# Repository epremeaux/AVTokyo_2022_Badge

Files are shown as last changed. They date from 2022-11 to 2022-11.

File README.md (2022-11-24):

## AVTokyo 2022 event badge
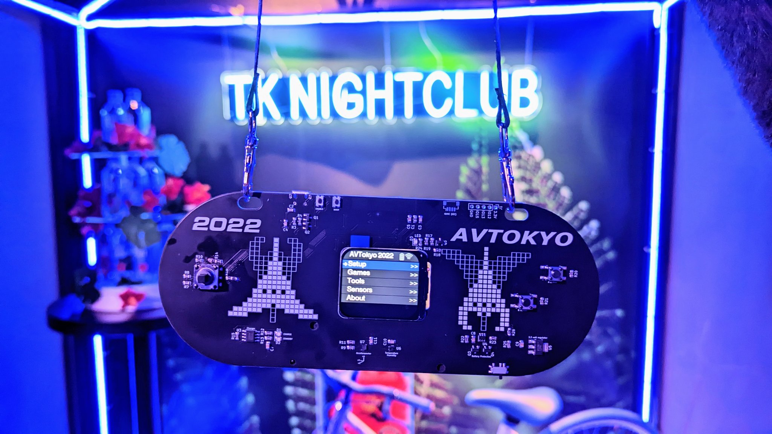
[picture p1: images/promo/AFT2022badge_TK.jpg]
Badge in front of the TKNightclub neon sign


### MQTT enabled, Hacker tools, Sensors and Games on ESP32
The AVTokyo 2022 event attendee badge was designed and produced by VPCAsia. Our vision was to provide a useful tool for the attendee not only at the event, but far into the future.

It is based on an 8MB ESP32 with 280x240 pixel TFT full color display (sourced from smart watches). Additionally, it includes a joystick (4 directions plus “press to select”), two game buttons (B and A), and two sensors (Temperature/Humidity and Accelerometer). Finally, the device is fully battery powered, relying on an 18650 style Li-ion battery with associated protections and USB charging.

The software runs a variety of open source Arduino libraries. In particular, we utilized [tcMenu](https://www.thecoderscorner.com/products/arduino-libraries/tc-menu/) and TFT_eSPI to provide all of our software UI, and Adafruit libraries to manage sensors and MQTT (Message Queue, Telemetry Transport).

While WiFi is connected and MQTT messaging is enabled, the badge will send Temperature, Humidity and Battery Voltage measurements to an MQTT server every 5 seconds (the interval is redefinable). Additionally, when you obtain a new best personal score on any game, the new score will be queued to be sent in the next MQTT post. While gaming, MQTT posting is temporarily disabled, in order to provide the best gaming experience.

Here is a video:
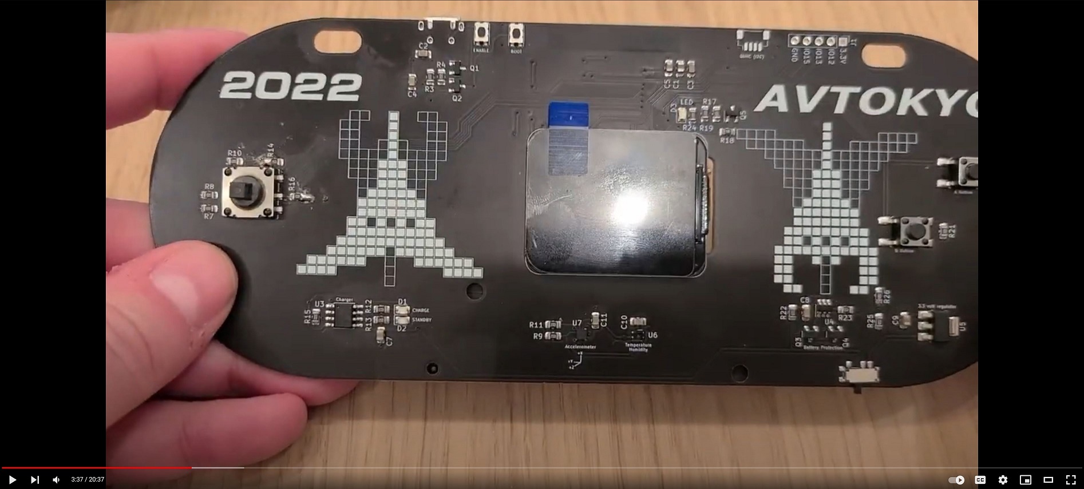
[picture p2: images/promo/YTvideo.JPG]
Watch the intro video (http://www.youtube.com/watch?v=L5FsP-4BdB0 "AVTokyo2022 Badge")


## Tour of the Board
Most of the badge components are self-explanatory, but I will attempt to highlight the main components and features. The circuitry between the joystick and screen is responsible for charging the battery (on the back). This is fed from the USB connector, and will charge the battery even when the badge is switched off. There are two LEDs, Standby and Charge. Once fully charged, the Charge LED will turn off and the Standby LED will light. These are rather bright! I started placing tape over my test units to dampend the brightness. ;)

Directly below the screen are the two sensors. On the right, we have an SHTC3 temperature and humidity sensor. On the left we have the KXTJ3-1057 accelerometer. Its not a particularly expensive device, so don't expect much. It's good enough for basic movement and orientation measurement. In the future, I hope to write some better drivers and filters for it to make the data more usable. At which point, I'll try to make a game using tilt/movement.

Above the power switch (bottom right) we have the battery protection circuits and voltage regulator which powers the board. The protection circuit is a very basic back to back mosfet configuration. The control IC *Should* cut power when the battery voltage gets below 3.2, but in my testing this turned out not to be the case. So, until I perform further tests, please dont trust this circuit to protect your battery from long term discharge. Remove the battery for storage.

Speaking of that power switch....   :(     Yes, now we know it's terrible. Attendee @mimura1133 found some alternate part numbers from Digikey if you have the skills to replace the switch. EG1215AA and CUS-12TB should fit. The part used on the badge is from G-Switch, MK-12C02-GXXX. We have yet to determine if this was a case of bad quality switches, or something in the reflow oven process made some of the switch plastics brittle. While this issue seemed considerable at the time of the event, we only had 42 total switch failures (of 400). The cracked resistor on the joystick was actually a higher failure rate.

Above the screen on the left we have the USB connector and associated ESP32 programming circuitry. This consists mainly of a USB to UART interface chip (CH340) and the Enable / Boot config buttons. Under normal circumstances using USB to program the badge, you should not need to bother with the buttons. If you get into a jam though, its nice to be able to manually trigger them. Additionally, the left button (enable) can be used as a reset button, so you dont have to toggle the power switch.
The USB connector can not only be used for programming but provides serial output from the ESP32 as well. There are some diagnostic messages as the badge goes through various tasks. The WiFi and Bluetooth scanners also output a lot of additional data here which cant possibly fit on the screen.

At the screen's top right corner we have a user LED and backlight control circuitry. The LED can be used for your own applications as well. We only use it to indicate the completion of the boot process (sort of a debugging tool for us).

Above the right side of the screen on the edge of the PCB we included some features for your own projects and future expansion. First, there is an I2C "Quiic" footprint. You will need to obtain and solder this yourself (was impossible at the time of production due to supply chain issues). This is a JST BM04B-SRSS connector or equivalent. 
To the right of the Quiic connector is a 5 pin header (2.54 mm pitch). This has ground, 3.3 volts, and three free GPIO from the ESP32. We are excited to see what you all come up with for these connections.

The back of the badge is dominated by the large 18650 lithium-ion battery holder at the bottom. Right in the middle is the ribbon cable for the screen. At top center we have the ESP32 module itself. This is an ESP32-Wroom-32 8MB part. Yes, it really IS 8MB. The firmware as flashed on the day of the event has a 4MB partition configuration. However, if you build fresh from this repository, it will build an 8Mb partition. All of our code now occupies only 20%! Lots of room left for more games, tools and custom apps. In the near future we will make some tutorials on how to add your project to the badge menu.

## Fixes to the production version
The PCB production and most of the component mounting was completed by JLCPCB. However, we still had some work to do. We glued the displays to the PCB and soldering the ribbon cable to the backside ourselves. Additionally, we mounted the battery case. However, you may notice some.. urr.. "Corrections" to some parts around the joystick. Unfortunately, I (Emery) made a mistake on the fill pattern, in which two pull-up resistors did not get connected to 3.3 Volts. So, we had to scrape away some of the solder mask and solder zero ohm jumpers to connect these resistors to the 3.3 volt fill. This added a LOT of additional work. The kicad files have been corrected. So if you attempt to produce the board yourself, don't worry.

We did experience a very unusual issue during production. Thankfully, I had created this a hardware test firmware before the final code was complete, so that we could test all functions before performing final firmware flashing. This test code included the Button Test (in the tools menu) as well as the Sensors page to confirm sensors were working.
The issue we found is that many (like, 1 of every 5 to 10) badges would indicate Left on the joystick, permanently. It took some time to identify the issue: The associated pull-up resistor (R8, on the left side of the joystick) was cracked. The crack is nearly impossible to see, even with a good magnifying lense. However, when we attempted to desolder it, it came off in two pieces! We were able to replace this resistor and managed to save 58 badges.

## About the Server
On our server side, we used a variety of services. It all starts by receiving the MQTT message in the MQTT server. From here, messages are written to a database using some custom Java.
From this database we then made web pages to output various statistics. In particular, we wanted to make a scoreboard for the two games included with the badge.
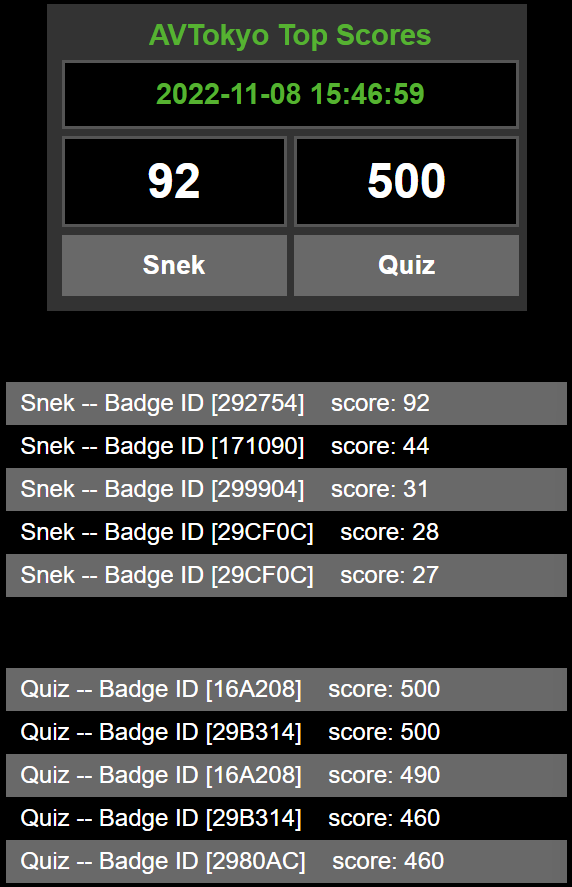
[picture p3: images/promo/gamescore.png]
Scores at the end of the event


MQTT is simply a message bucket service. Many other services can subscribe to it. In fact, the code which writes to the database simply subscribes to the MQTT messages. Because this concept is so flexible, other services can easily subscribe at the same time.

Node-Red is a very user friendly GUI based data application builder. It was a simple matter to create a Node-Red flow to subscribe to badge topics using wild cards, allowing us to easily gather temperature measurements from ALL badges at once for example. This same flow outputs a web page with gauges, plots and text data. Node-Red performance is not very quick, but because it is only subscribing to topics (and another service handles database work), it has no impact on MQTT or our database.
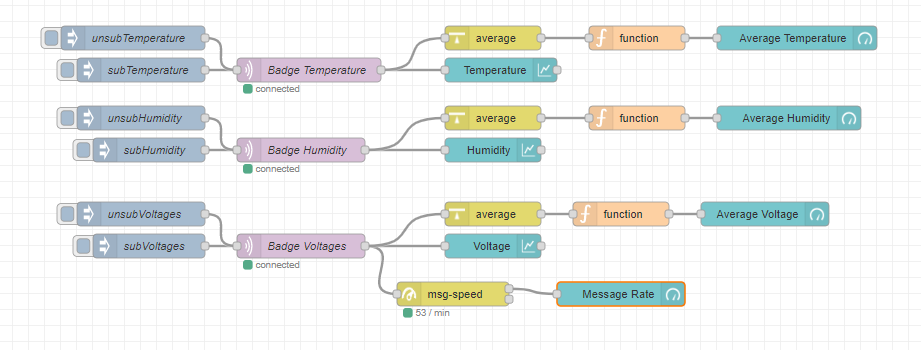
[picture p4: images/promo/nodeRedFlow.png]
Node-Red Flow

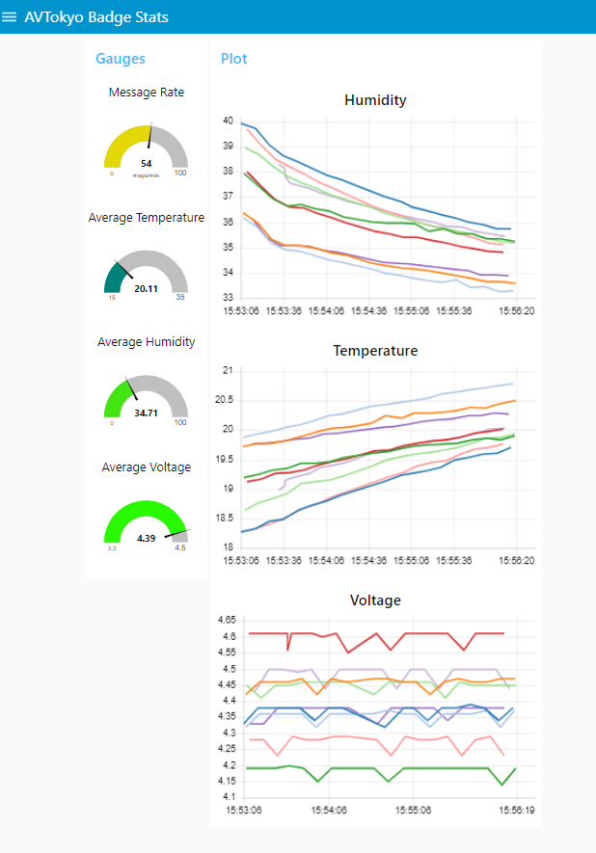
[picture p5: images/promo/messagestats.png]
Node-Red statistics page


### WiFi BugHunt
WE had one more game to play at the event: a WiFi BugHunt! These consisted of an ESP32 with battery pack hidden inside the nightclub (see AVTokyo_2022_Badge/Software/AVT_FindMe_Switcher/). Using the WiFi scanner tool in the badge (or your smartphone), players could seek out the three hidden WiFi access points. Once found, there was a QR code printed on the container of the WiFi AP. Scanning the code with your smartphone would bring you to a guest book web page, where you could sign that you found the AP and leave a comment. To make it more challenging, the APs occasionally dropped AP mode and joined local WiFi to send us an MQTT message containing the battery voltage, so we could monitor the devices in real time. It was quite entertaining to see all the script attacks people tried on our guestbook page ;)
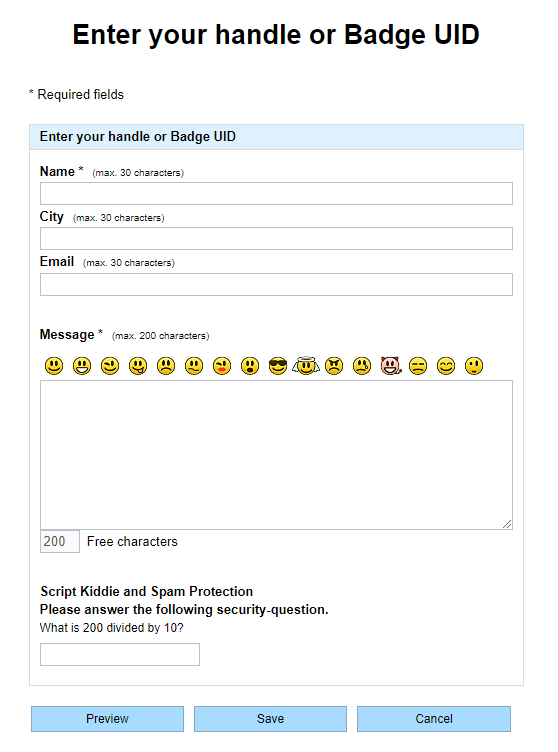
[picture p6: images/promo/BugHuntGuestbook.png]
BugHunt form

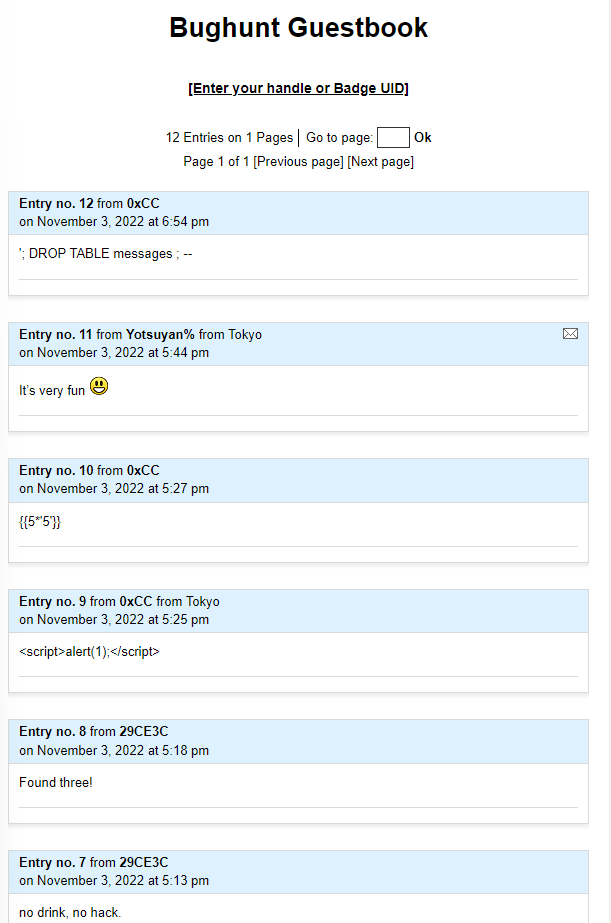
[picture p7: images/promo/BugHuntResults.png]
BugHunt results


## Getting the code up and running
The source code is "almost ready to run". You will need to install an editor such as Visual Studio Code. Within VSCode, add the PlatformIO extension. After opening the sourcecode folder, PlatformIO SHOULD download all the required extensions (mainly the Arduino framework and the ESP32 platform). All the required libraries are already included in the source code folder (.pio/libdeps/esp32dev/).
Depending on your initial VSCode and PlatformIO configuration, you MAY need to add "lorol/LittleFS_esp32@^1.0.6" to the platform.ini file, under the "lib_deps = " heading. If during compile you receive errors concerning LittleFS, either add it to the platform.ini file, or remove it (just add ; to the beginning of the line).

Additionally, you will need to create a "secrets.h" file like so:
```

//wifi
#define SECRET_SSID "your first AP"
#define SECRET_PASS "AP1 password"

#define SECRET_SSID2 "Second AP"
#define SECRET_PASS2 "AP2 password"

#define SECRET_SSID3 "third AP"
#define SECRET_PASS3 "AP3 password"

//mqtt
#define SECRET_SERVER "MQTT URL or IP" 

```

You can add as many WiFi access points as you want. Look at the MyWiFi.cpp file to add them to the array. The badge will first try to connect to whatever AP you have saved manually from the menu system. If that connection fails, it will then scan through the list given at the top of MyWiFi.cpp (the list is filled in from the secrets.h file). It will try to match any of these AP names to a scanned list available. If one matches, it will try to connect.

In addition to WiFi, you may want to point the badge to your own MQTT server. You may enter it manually in the menu, but you may prefer to hard code it. We have only defined the SECRET_SERVER keyword in the secrets.h file. This assumes an unsecured connection. So, you may want to modify MQTT_Sensors.cpp and secrets.h such that you can define a username and access key in secrets.h.

### UPDATE (22/11/24):

While experimenting with some badges, I found that SOME badges have 4MB ESP32 modules, and some have 8MB modules. Of course, we ORDERED 8MB modules. If you are attempting to compile and run this code and the following effects happen (after upload and reset), you likely have a 4MB module:

* red LED at the top right corner of the screen remains dimly light
* nothing displayed on screen
* when using the terminal, you see that the ESP is rapidly rebooting, with the following output: 
```
rst:0x3 (SW_RESET),boot:0x13 (SPI_FAST_FLASH_BOOT)
configsip: 0, SPIWP:0xee
clk_drv:0x00,q_drv:0x00,d_drv:0x00,cs0_drv:0x00,hd_drv:0x00,wp_drv:0x00
mode:DIO, clock div:2
load:0x3fff0030,len:1184
load:0x40078000,len:12776
load:0x40080400,len:3032
entry 0x400805e4
ets Jul 29 2019 12:21:46
```

PlatformIO is building an image set larger than the size of the flash storage area. However, it cannot by itself, verify the size. All the checksums are fine. You can confirm the size of your ESP's flash area yourself though. Look in the upload task terminal. When you hit the compile button (check mark on the bottom of VSCode window), one of hte first few lines will read:
HARDWARE: ESP32 240MHz, 320KB RAM, 4MB Flash
OR
HARDWARE: ESP32 240MHz, 320KB RAM, 8MB Flash

IF you were unlucky enough to get a 4MB module, we are so sorry.. but we cant control unscrupulous suppliers *(
What to do:
in the platformio.ini file, find the line which reads:

```
board_build.partitions = AVT_8MB_huge.csv
```

Change it to read:

```
board_build.partitions = huge_app.csv
```

This will use a standard partition table for a 4MB ESP32, where most of the space is devoted to a single app, plus bootloader. The base AVT code will occupy 51.5%, still leaving plenty of space for future enhancements.
By the way, this partition table is the one used in all of the badges on the day of the event. This is why I did not notice that we had a mix of 4MB and 8MB modules. So, I dont know yet what the statistics are on how many of you have each type.

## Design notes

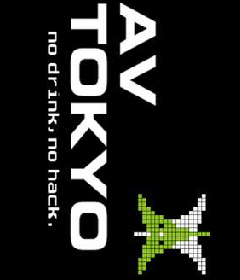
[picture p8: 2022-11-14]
images/pictures/ndnh277.png

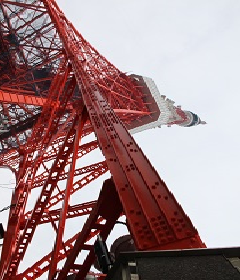
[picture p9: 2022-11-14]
images/pictures/TT1.png

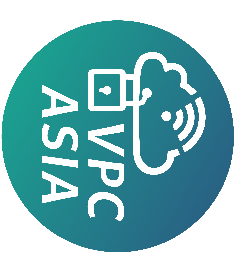
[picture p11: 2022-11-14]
images/pictures/VPCA.png

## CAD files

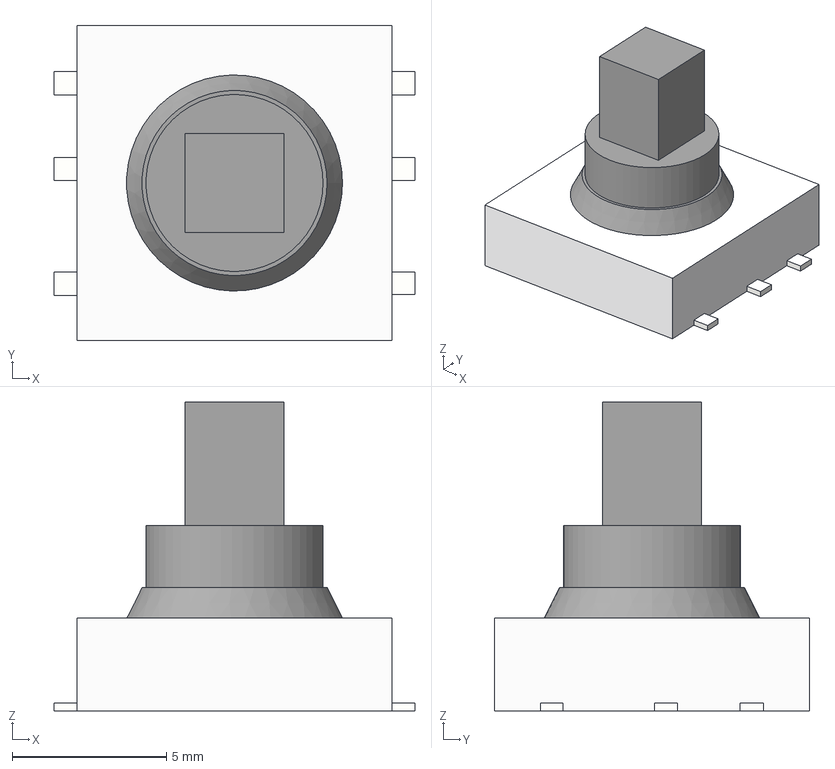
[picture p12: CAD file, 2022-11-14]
Kicad/3dmodels/AVTokyo/HROParts Multi-direction switch K1-1506SN-01.step
11.7 x 10.2 x 10.0 mm
stick
leads

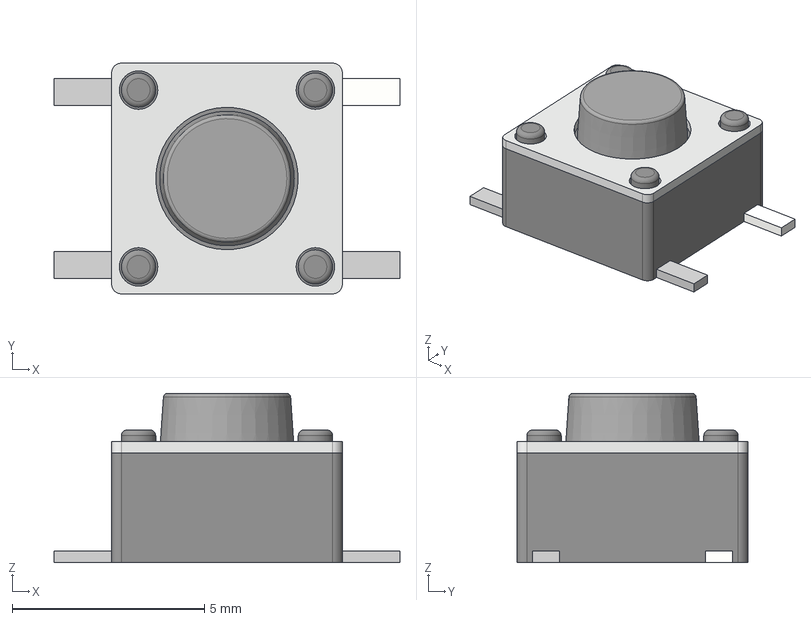
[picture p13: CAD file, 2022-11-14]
Kicad/3dmodels/AVTokyo/tact switch KH-6x6x5H v2.step
9.00 x 6.00 x 4.40 mm
toop plate
button
legs

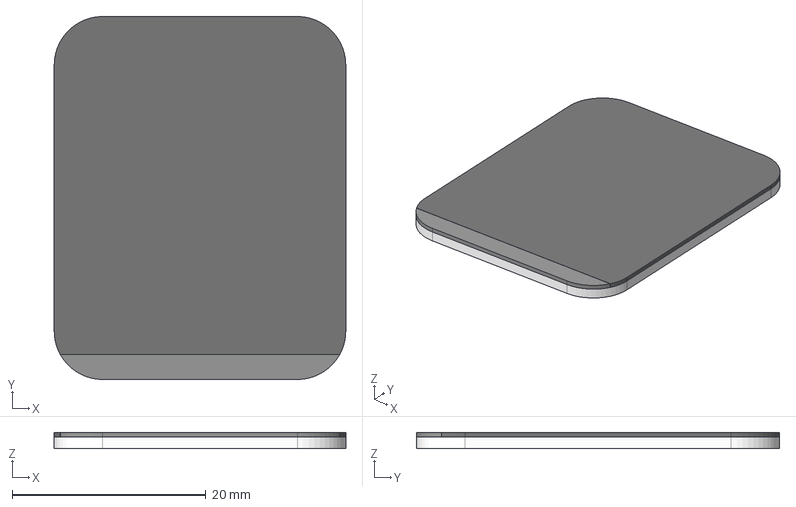
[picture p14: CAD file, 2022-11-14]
Kicad/3dmodels/AVTokyo/1.69 inch 240x280 v1.step
30.1 x 37.4 x 1.70 mm
LED Plate
glass
driverstrip

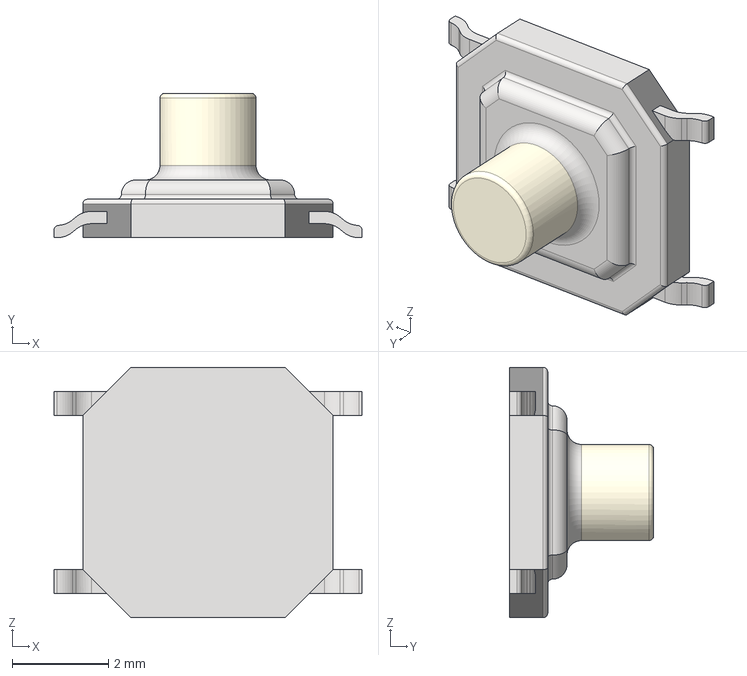
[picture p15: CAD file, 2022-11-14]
Kicad/3dmodels/AVTokyo/tact_switch_3mm.stp
6.40 x 3.00 x 5.20 mm

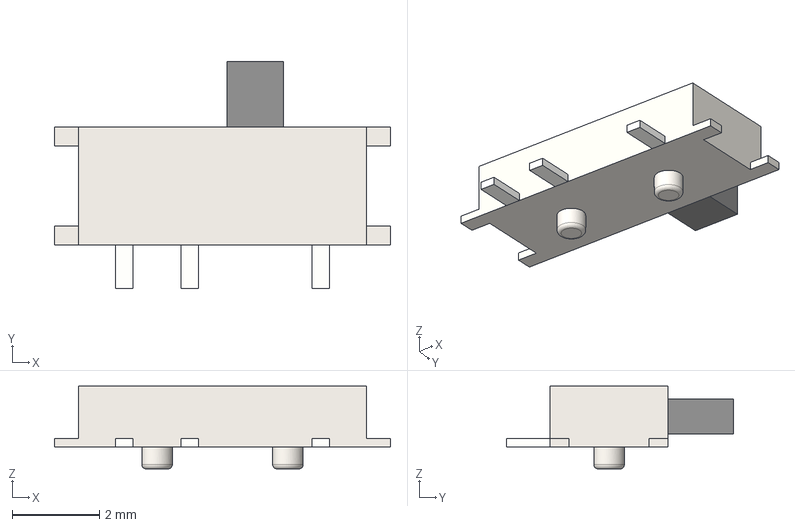
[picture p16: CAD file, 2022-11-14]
Kicad/3dmodels/AVTokyo/G-Switch MK-12C02-Gxxx.step
7.70 x 5.20 x 1.90 mm
Terminals
knob

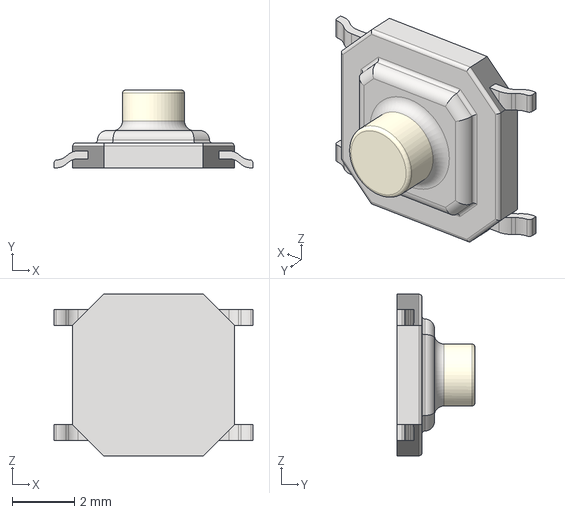
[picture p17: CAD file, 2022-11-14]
Kicad/3dmodels/AVTokyo/tact_switch_2.5mm.stp
6.40 x 2.50 x 5.20 mm

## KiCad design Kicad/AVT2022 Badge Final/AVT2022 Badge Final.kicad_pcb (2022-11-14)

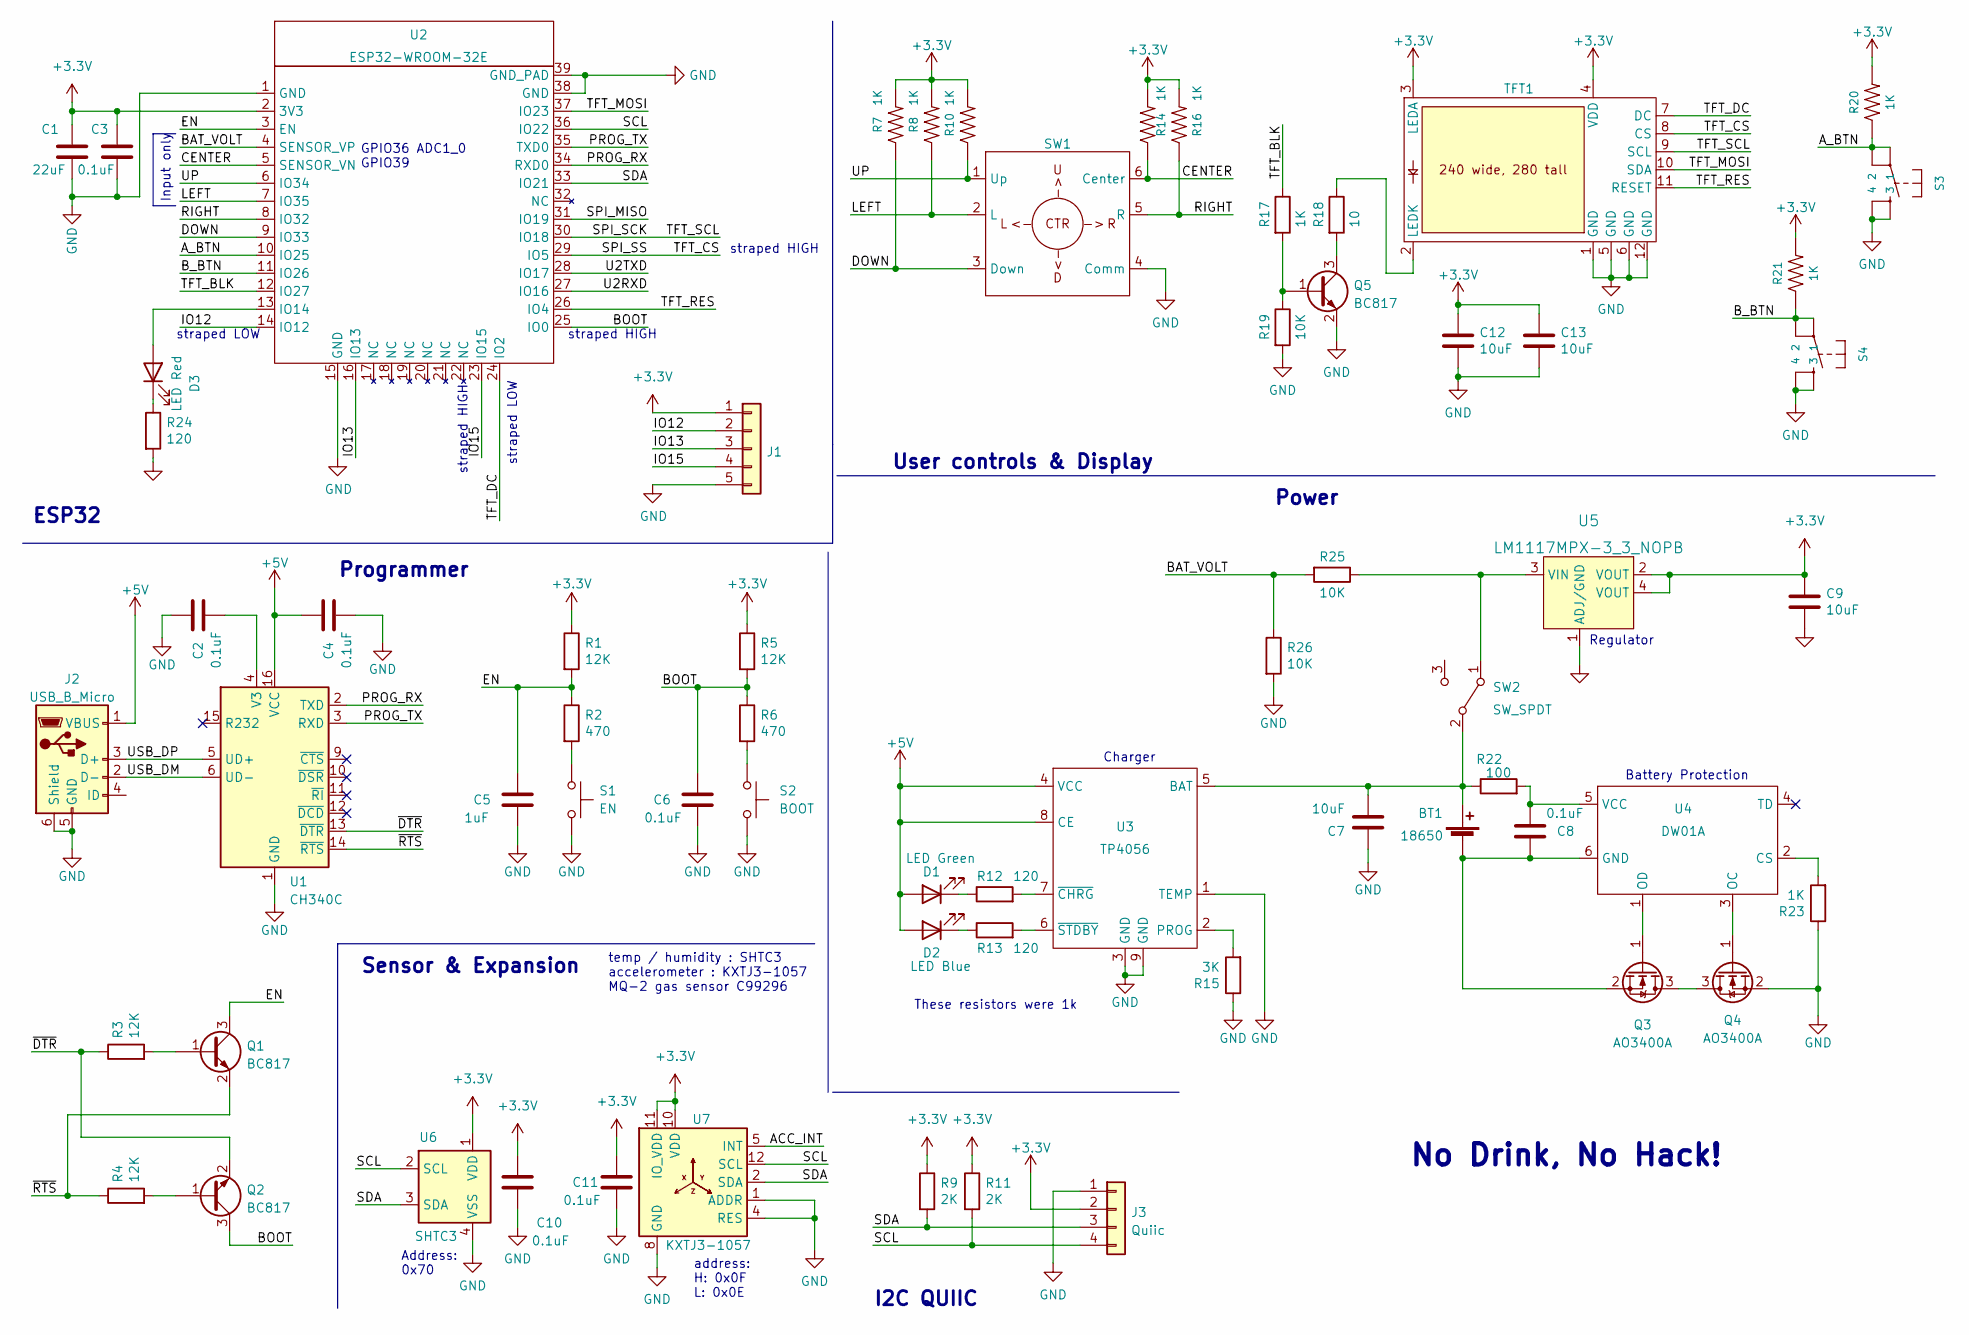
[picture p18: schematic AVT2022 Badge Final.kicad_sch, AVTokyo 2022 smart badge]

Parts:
BT1: 18650; BatteryHolder_Keystone_1042_1x18650; JLCPCB Status DO NOT POPULATE
C1: 22uF; C_0805_2012Metric_Pad1.18x1.45mm_HandSolder; JLCPCB# C89572
C2, C3, C4, C6, C8, C10, C11: 0.1uF; C_0805_2012Metric_Pad1.18x1.45mm_HandSolder; JLCPCB# C49678
C5: 1uF; C_0805_2012Metric_Pad1.18x1.45mm_HandSolder; JLCPCB# C28323
C7, C9, C12, C13: 10uF; C_0805_2012Metric_Pad1.18x1.45mm_HandSolder; JLCPCB# C15850
D1: LED Green; LED_0805_2012Metric; JLCPCB Status extended
D2: LED Blue; LED_0805_2012Metric; JLCPCB Status basic
D3: LED Red; LED_0805_2012Metric; JLCPCB Status basic
J1: Conn_01x05; PinHeader_1x05_P2.54mm_Vertical; JLC_Status DO NOT POPULATE
J2: USB_B_Micro; USB_Micro-AB_Molex_47590-0001; JLCPCB Status extended
J3: Quiic; JST_SH_BM04B-SRSS-TB_1x04-1MP_P1.00mm_Vertical; JLC_Status DO NOT POPULATE
Q1, Q2, Q5: BC817; SOT-23; JLCPCB Status extended
Q3, Q4: AO3400A; SOT-23; JLCPCB Status basic
R1, R3, R4, R5: 12K; R_0805_2012Metric_Pad1.20x1.40mm_HandSolder; JLCPCB# C17444
R2, R6: 470; R_0805_2012Metric_Pad1.20x1.40mm_HandSolder; JLCPCB# C17710
R7, R8, R10, R14, R16, R17, R20, R21, R23: 1K; R_0805_2012Metric_Pad1.20x1.40mm_HandSolder; JLCPCB# C17513
R9, R11: 2K; R_0805_2012Metric_Pad1.20x1.40mm_HandSolder; JLCPCB# C17604
R12, R13, R24: 120; R_0805_2012Metric_Pad1.20x1.40mm_HandSolder; JLCPCB# C17437
R15: 3K; R_0805_2012Metric_Pad1.20x1.40mm_HandSolder; JLCPCB# C17661
R18: 10; R_0805_2012Metric_Pad1.20x1.40mm_HandSolder; JLCPCB# C176204
R19, R25: 10K; R_0805_2012Metric_Pad1.20x1.40mm_HandSolder; JLCPCB# C17414
R22: 100; R_0805_2012Metric_Pad1.20x1.40mm_HandSolder; JLCPCB# C17408
R26: 10K; R_0805_2012Metric_Pad1.20x1.40mm_HandSolder; JLCPCB# C17621
S1: EN; SW_Push_1P1T_NO_CK_KMR2; JLCPCB Status extended
S2: BOOT; SW_Push_1P1T_NO_CK_KMR2; JLCPCB Status extended
S3, S4: MOMENTARY-SWITCH-SPST-2-SMD-5.2MM; Switch_Tactile_SMD_6x6mm; JLCPCB Status extended
SW1: navigation_switch_K1-1506SN-01; K1-1506SN-01; JLCPCB Status extended
SW2: SW_SPDT; MK-12C02-Gxxx SPDT SMD switch; JLCPCB Status extended
TFT1: TFT_240x280_raw_LH169I-IG01; TFT_240x280_raw_LH169I-IG01_BackSideMount; JLC_Status DO NOT POPULATE
U1: CH340C; SOIC-16_3.9x9.9mm_P1.27mm; JLCPCB Status extended
U2: ESP32-WROOM-32E; JLCPCB Status extended
U3: TP4056; TI_SO-PowerPAD-8; JLCPCB Status extemded
U4: DW01A; SOT-23-6; JLCPCB Status extemded
U5: LM1117MPX-3_3_NOPB; SOT-223; MPN LM1117MPX-3.3/NOPB; Digi-Key_PN LM1117MPX-3.3/NOPBCT-ND
U6: SHTC3; Sensirion_DFN-4-1EP_2x2mm_P1mm_EP0.7x1.6mm; JLCPCB# C194656
U7: KXTJ3-1057; Kionix_LGA-12_2x2mm_P0.5mm_LayoutBorder2x4y; JLCPCB# C442603

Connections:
+3.3V: C1.1, C3.1, C9.1, C10.1, C11.1, C12.1, C13.1, J1.1, J3.2, R1.1, R5.1, R7.2, R8.2, R9.1, R10.2, R11.1, R14.2, R16.2, R20.2, R21.2, TFT1.3 (LEDA), TFT1.4 (VDD), U2.2 (3V3), U5.2 (VOUT), U5.4 (VOUT), U6.1 (VDD), U7.3 (IO_VDD), U7.7 (VDD), U7.10 (VDD), U7.11 (IO_VDD)
+5V: C4.1, D1.2 (A), D2.2 (A), J2.1 (VBUS), U1.16 (VCC), U3.4 (VCC), U3.8 (CE)
/ACC_INT: U7.5 (INT)
/A_BTN: R20.1, S3.1, S3.2, U2.10 (IO25)
/BAT_VOLT: R25.2, R26.1, U2.4 (SENSOR_VP)
/BOOT: C6.1, Q2.3 (C), R5.2, R6.1, U2.25 (IO0)
/B_BTN: R21.1, S4.1, S4.2, U2.11 (IO26)
/CENTER: R14.1, SW1.6 (Center), U2.5 (SENSOR_VN)
/DOWN: R7.1, SW1.3 (Down), U2.9 (IO33)
/EN: C5.1, Q1.3 (C), R1.2, R2.1, U2.3 (EN)
/IO12: J1.2, U2.14 (IO12)
/IO13: J1.3, U2.16 (IO13)
/IO15: J1.4, U2.23 (IO15)
/LEFT: R8.1, SW1.2 (L), U2.7 (IO35)
/PROG_RX: U1.2 (TXD), U2.34 (RXD0)
/PROG_TX: U1.3 (RXD), U2.35 (TXD0)
/RIGHT: R16.1, SW1.5 (R), U2.8 (IO32)
/SCL: J3.4, R11.2, U2.36 (IO22), U6.2 (SCL), U7.12 (SCL)
/SDA: J3.3, R9.2, U2.33 (IO21), U6.3 (SDA), U7.2 (SDA)
/SPI_MISO: U2.31 (IO19)
/SPI_SCK: TFT1.9 (SCL), U2.30 (IO18)
/SPI_SS: TFT1.8 (CS), U2.29 (IO5)
/TFT_BLK: R17.1, U2.12 (IO27)
/TFT_DC: TFT1.7 (DC), U2.24 (IO2)
/TFT_MOSI: TFT1.10 (SDA), U2.37 (IO23)
/TFT_RES: TFT1.11 (RESET), U2.26 (IO4)
/U2RXD: U2.27 (IO16)
/U2TXD: U2.28 (IO17)
/UP: R10.1, SW1.1 (Up), U2.6 (IO34)
/USB_DM: J2.2 (D-), U1.6 (UD-)
/USB_DP: J2.3 (D+), U1.5 (UD+)
/~DTR: Q2.2 (E), R3.1, U1.13 (~DTR)
/~RTS: Q1.2 (E), R4.1, U1.14 (~RTS)
GND: C1.2, C2.1, C3.2, C4.2, C5.2, C6.2, C7.1, C9.2, C10.2, C11.2, C12.2, C13.2, J1.5, J2.5 (GND), J2.6 (Shield), J3.1, Q4.2 (S), Q5.2 (E), R15.1, R19.2, R23.1, R24.2, R26.2, S1.2, S2.2, S3.3, S3.4, S4.3, S4.4, SW1.4 (Comm), TFT1.1 (GND), TFT1.5 (GND), TFT1.6 (GND), TFT1.12 (GND), U1.1 (GND), U2.1 (GND), U2.15 (GND), U2.38 (GND), U2.39 (GND_PAD), U3.1 (TEMP), U3.3 (GND), U3.9 (GND), U5.1 (ADJ/GND), U6.4 (VSS), U7.1 (ADDR), U7.4 (RES), U7.6 (GND), U7.8 (GND), U7.9 (GND)
unnamed: BT1.1 (+), C7.2, R22.1, SW2.2 (B), U3.5 (BAT)
unnamed: BT1.2 (-), C8.1, Q3.2 (S), U4.6 (GND)
unnamed: C2.2, U1.4 (V3)
unnamed: C8.2, R22.2, U4.5 (VCC)
unnamed: D1.1 (K), R12.1
unnamed: D2.1 (K), R13.1
unnamed: D3.1 (K), R24.1
unnamed: D3.2 (A), U2.13 (IO14)
unnamed: Q1.1 (B), R3.2
unnamed: Q2.1 (B), R4.2
unnamed: Q3.1 (G), U4.1 (OD)
unnamed: Q3.3 (D), Q4.3 (D)
unnamed: Q4.1 (G), U4.3 (OC)
unnamed: Q5.1 (B), R17.2, R19.1
unnamed: Q5.3 (C), R18.2
unnamed: R2.2, S1.1
unnamed: R6.2, S2.1
unnamed: R12.2, U3.7 (~CHRG)
unnamed: R13.2, U3.6 (~STDBY)
unnamed: R15.2, U3.2 (PROG)
unnamed: R18.1, TFT1.2 (LEDK)
unnamed: R23.2, U4.2 (CS)
unnamed: R25.1, SW2.1 (A), U5.3 (VIN)

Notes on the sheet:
straped HIGH
straped LOW
ESP32
Charger
GPIO36 ADC1_0 GPIO39
Regulator
temp / humidity : SHTC3 accelerometer : KXTJ3-1057 MQ-2 gas sensor C99296
Power
Address: 0x70
Input only
Battery Protection
These resistors were 1k
address: H: 0x0F L: 0x0E
Programmer
I2C QUIIC
No Drink, No Hack!
Sensor & Expansion
User controls & Display

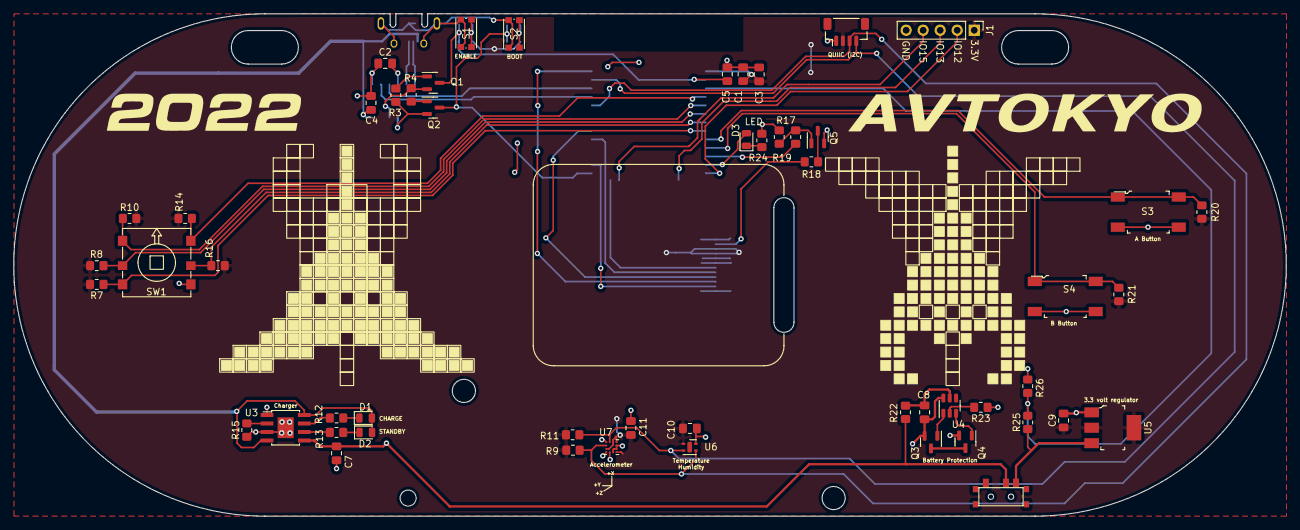
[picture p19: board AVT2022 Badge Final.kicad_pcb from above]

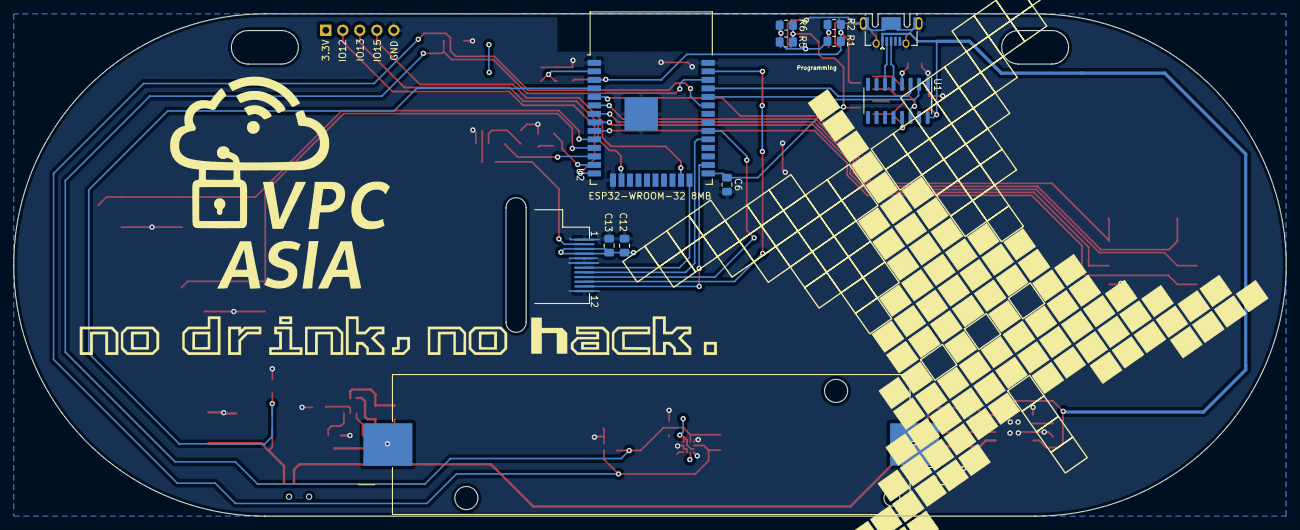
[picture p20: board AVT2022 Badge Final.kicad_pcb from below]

Board: 2 copper layers, 190.0 x 75.0 mm, 65 parts (11 on the bottom side), 53 nets.

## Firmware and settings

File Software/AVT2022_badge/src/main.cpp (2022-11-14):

#include <Arduino.h>
#include "AVT2022_badge_menu.h"
#include "TFT_eSPI.h"

//#include our application header files
#include "variables.h"
#include "MyWiFi.h"
#include "ButtonIcons.h"
#include "BatteryWidget25x15.h"
#include "WiFiWidget28x20.h"
#include "life.h"
#include "scanner.h"
#include "quiz.h"
#include "snek.h"
#include "Plotter.h"
#include "MQTT_Sensors.h"
#include "SaveScreen.h"
#include "Preferences.h"
// images
#include "avtokyo.h"
#include "vpcasia.h"

#define MAX_IMAGE_WIDTH 240
#define MAX_IMAGE_HEIGHT 280

Preferences Global::preferences;
// Note: Key name is limited to 15 chars.
// preferences / user
String UserName;
// preferences / system
int BackLight;
int BadgeMode;

int WifiConnected = false;

int Global::FWversion = 1;

// preferences / games
// preferences / scores

uint16_t Global::TODcounter = 0;

// hardware config
#define RIGHT_PIN 32 // 36
#define DOWN_PIN 33
#define UP_PIN 34
#define LEFT_PIN 35
#define SELECT_PIN 39
#define A_PIN 25 // A button
#define B_PIN 26
#define USR_LED 14

// backlight dimming
#define BACKLIGHT_PIN 27
const int freq = 1000;
const int ledChannel = 0;
const int resolution = 8;

/************ Titlebar Widgets ******************/
//  padding widget to push icons left. Make this the last widget in chain
TitleWidget BatteryWidget(iconsBattery, 5, 15, 25);
TitleWidget WiFiWidget(iconsWiFi, 5, 28, 20, &BatteryWidget);
TitleWidget iconspadWidget(iconsWiFi, 5, 16, 12, &WiFiWidget);


/************ Configuring WiFi ******************/
char Global::WLAN_SSID[]; // changable ssid and pw
char Global::WLAN_PASS[];
bool Global::WiFi_Enable = true; // true = wifi enabled
bool Global::WiFi_Good = false;
bool Global::WiFi_DoReset = true;
bool Global::WiFi_DoDisable = false;
char Global::USER_ID[];


/************ TASK IDs ******************/
taskid_t Global::SenserUpdateTaskID;
taskid_t Global::ConnectWiFiTaskID;
taskid_t Global::PostMQTTTaskID;




/****************************************************************************
 *                      Helper functions
 ****************************************************************************/
void showImages()
{
    gfx.fillScreen(TFT_BLACK);
    gfx.pushImage(0, 0, MAX_IMAGE_WIDTH, MAX_IMAGE_HEIGHT, (uint8_t *)avtokyo_logo, true);
    delay(3500);
    gfx.fillScreen(TFT_BLACK);
    gfx.pushImage(0, 0, MAX_IMAGE_WIDTH, MAX_IMAGE_HEIGHT, (uint8_t *)vpcasia_logo, true);
    delay(3500);
    gfx.fillScreen(TFT_BLACK);
}


void ResetScreen(unsigned int encoderValue, RenderPressMode clicked)
{       // draws a screen to tell user the factory defaults have been restored
    if (Global::TODcounter == 0)
    {
        Global::TODcounter++;
        gfx.fillScreen(TFT_BLACK);
        gfx.setTextSize(1);
        gfx.setTextColor(TFT_WHITE);
        gfx.setCursor(50, 10);
        gfx.println("Factory settings");
        gfx.println("         restored");
    }
    delay(1000);
    Global::TODcounter = 0;
    renderer.giveBackDisplay();
}


void WipeAllPrefs()
{
    // clears out all preference namespaces.
    // upon reboot, the defaults will be re-applied
    Global::preferences.begin("User", false);
    Global::preferences.clear();
    Global::preferences.end();

    Global::preferences.begin("Network", false);
    Global::preferences.clear();
    Global::preferences.end();

    Global::preferences.begin("System", false);
    Global::preferences.clear();
    Global::preferences.end();

    Global::preferences.begin("MQTT", false);
    Global::preferences.clear();
    Global::preferences.end();

    Global::preferences.begin("Quiz", false);
    Global::preferences.clear();
    Global::preferences.end();

    Global::preferences.begin("Snek", false);
    Global::preferences.clear();
    Global::preferences.end();
    // nitification screen
    renderer.takeOverDisplay(ResetScreen);
}

void onPressed(uint8_t pin, bool heldDown)
{
    // This function must exist, even if it needs no additional code
    // it allows all of our buttons to be available to decode in games/tools
    // we can also do stuff like below, but this would print on every press.. its better to decode as needed in the game/tool
    // we also MUST have the below class (MyKeyListener), even though its empty.
    // in setup, we will add all the additional buttons we want to listen for and decode

    /* if (pin == A_PIN){
       Serial.println("A button polled");
     }
     if (pin == B_PIN){
       Serial.println("B button polled");
     }  */
}

class MyKeyListener : public SwitchListener
{
public:
    void onPressed(uint8_t pin, bool held) override
    {
    }

    void onReleased(uint8_t /*pin*/, bool held) override
    {
        // Called on key release
    }
} keyListener;



// some vars to cycle title widgets until code written to control them...
int widgetCounter = 0;
bool widgetDirUp = true;

void updateIconsTask()
{
    /* Battery range
     * From 4.25V to 3.6 volts
     * However the screen flickers a LOT and becomes very dim
     * Practical range is from 4.25 to 3.86V
     */
    // cludgy fix for the battery range. Voltage divider is not precision, and ESP32 ADC is terrible
    float BAT_HIGHVAL = 4.25;

    float batVal = Global::BatteryVoltage;
    // cludge gear ENGAGE!!
     if (batVal > BAT_HIGHVAL) {
        batVal = BAT_HIGHVAL;
    }
    int BatSetIcon;
    if(batVal > 4.1) {
        BatSetIcon = 4;
    } else if (batVal > 4.0) {
        BatSetIcon = 3;
    } else if (batVal > 3.8) {
        BatSetIcon = 2;
    } else if (batVal > 3.6) {
        BatSetIcon = 1;
    } else {
        BatSetIcon = 0;
    }
    BatteryWidget.setCurrentState(BatSetIcon);


    int wifiIconVal;
    if (WiFi.status() == WL_CONNECTED) {
        wifiIconVal = map(WiFi.RSSI(), -100, -50, 0, 4);
    } else {
        wifiIconVal = 0;
    }
    WiFiWidget.setCurrentState(wifiIconVal);
    // https://www.netspotapp.com/wifi-signal-strength/what-is-rssi-level.html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,-As%20we've&text=The%20higher%20the%20RSSI%20value,is%20no%20signal%20at%20all.
}

/****************************************************************************
 *                      Menu Callbacks!
 * 
 * These callbacks are used by the menu task when you activate or change
 * a menu item. Not all menu items have callbacks. They set at design time
 * with tcMenuDesigner tool, and defined in _menu.cpp and _menu.h
 * Empty callbacks may be eliminated in the future. Its not always easy
 * to predict up front if you REALLY need a callback or not.
 * 
 ****************************************************************************/

/****************************************************************************
 *                      BASIC SETTINGS (SETUP)
 ****************************************************************************/
void CALLBACK_FUNCTION setBadgeMode(int id)
{
    // empty callback. 
}

void CALLBACK_FUNCTION setBacklight(int id)
{
    BackLight = menuSetupBacklight.getCurrentValue();
    // map 0-9 to 10-255
    int set = map(BackLight, 0, 9, 10, 255);
    ledcWrite(ledChannel, set);
}

void CALLBACK_FUNCTION ResetPreferences(int id)
{
    WipeAllPrefs();
}


/****************************************************************************
 *                      WIFI
 ****************************************************************************/

void CALLBACK_FUNCTION setWiFiEnable(int id)
{
    if (menuSetupWiFiEnableWiFi.getBoolean() == true)
    { 
        Global::WiFi_DoReset = true;
    }
    else
    { 
        Global::WiFi_DoDisable = true;
    }
}

void CALLBACK_FUNCTION setSSID(int id)
{
    // TODO - your menu change code
}

void CALLBACK_FUNCTION setWiFiPassword(int id)
{
    // TODO - your menu change code
}

void CALLBACK_FUNCTION saveWifi(int id)
{
    saveWiFiSettings();

    renderer.takeOverDisplay(SavedScreen);
}

/****************************************************************************
 *                      SETUP SAVE
 ****************************************************************************/

void CALLBACK_FUNCTION SetupSave(int id)
{
    // read the settings from menu
    UserName = menuSetupName.getTextValue();
    BackLight = menuSetupBacklight.getCurrentValue();
    BadgeMode = menuSetupBadgeMode.getCurrentValue();

    // save user settings
    Global::preferences.begin("User", false);
    Global::preferences.putString("UserName", UserName);
    Global::preferences.end();

    // save system settings
    Global::preferences.begin("System", false);
    Global::preferences.putInt("BackLight", BackLight); // write the value
    Global::preferences.putInt("BadgeMode", BadgeMode); // Enable this line AFTER you have the escape back to menu funtions in these modes.
    Global::preferences.end();

    // draw a screen to alert the user that settings are saved.
    renderer.takeOverDisplay(SavedScreen);
}

/****************************************************************************
 *                      MQTT
 ****************************************************************************/

void CALLBACK_FUNCTION setMQTTEnable(int id)
{
    if (menuSetupMQTTEnable.getCurrentValue() == true)
    { // re-enable the wifi connect task
      // crsx     taskManager.setTaskEnabled(Global::PostMQTTTaskID, true);
      //      Serial.println("enabled MQTT post task");
    }
    else
    { // disable the wifi connect task
        taskManager.setTaskEnabled(Global::PostMQTTTaskID, false);
        Serial.println("disabled MQTT post task");
    }
}

void CALLBACK_FUNCTION setMQTTBroker(int id)
{
    // TODO - your menu change code
}

void CALLBACK_FUNCTION setMQTTPort(int id)
{
    // TODO - your menu change code
}

void CALLBACK_FUNCTION setMQTTPostInterval(int id)
{
    // TODO - your menu change code
}

void CALLBACK_FUNCTION saveMQTT(int id)
{
    SaveMQTTsettings();
    renderer.takeOverDisplay(SavedScreen);
}

/****************************************************************************
 *                      GAMES
 ****************************************************************************/
void CALLBACK_FUNCTION LaunchGameOfLife(int id)
{
    Serial.println();
    Serial.println("launch GOL");

    Global::TODcounter = 0;
    renderer.takeOverDisplay(create_life);
}

void CALLBACK_FUNCTION LaunchSnek(int id)
{
    Serial.println();
    Serial.println("launching Snek");

    Global::TODcounter = 0;
    renderer.takeOverDisplay(snek_game);
}


void CALLBACK_FUNCTION launchQuiz(int id)
{
    Global::TODcounter = 0;
    renderer.takeOverDisplay(new_quiz);
}

/****************************************************************************
 *                      TOOLS
 ****************************************************************************/
void CALLBACK_FUNCTION LaunchWiFiScanner(int id)
{
    Global::WiFi_DoDisable = true;
    renderer.takeOverDisplay(new_WiFi_scan);
}

void CALLBACK_FUNCTION launchBLEScan(int id)
{
    Global::WiFi_DoDisable = true;
    renderer.takeOverDisplay(new_Bluetooth_scan);
}

/*******************  BUTTON TESTER  ********************************/

void CALLBACK_FUNCTION LaunchButtonTest(int id)
{
    // ButtonTester app is part of the ButtonIcons.cpp
    renderer.takeOverDisplay(ButtonTester);
}

/****************************************************************************
 *                      SENSORS
 ****************************************************************************/

void CALLBACK_FUNCTION PlotTemperature(int id)
{
    renderer.takeOverDisplay(drawTemperaturePlot);
}

void CALLBACK_FUNCTION PlotHumidity(int id)
{
    renderer.takeOverDisplay(drawHumidityPlot);
}

void CALLBACK_FUNCTION PlotIMU(int id)
{
        renderer.takeOverDisplay(drawIMUPlot);
}

/****************************************************************************
 *                      ABOUT
 ****************************************************************************/
int aboutState = 0;
void AboutCallback(unsigned int encoderValue, RenderPressMode clicked)
{
    // At this point clicked is the status of the select button
    // it can be RPRESS_NONE, RPRESS_PRESSED or RPRESS_HELD
    // encoderValue is the current value of the rotary encoder

    switch (aboutState)
    {
    case 0:
    {
        gfx.fillScreen(TFT_BLACK);
        gfx.setTextSize(1);
        gfx.setTextColor(TFT_WHITE);
        gfx.setCursor(0, 5);
        gfx.setTextColor(TFT_GREEN);
        gfx.print(F("   PCB: "));
        gfx.setTextColor(TFT_WHITE);
        gfx.println(F("Emery Premeaux"));
        gfx.setCursor(0, 35);
        gfx.setTextColor(TFT_RED);
        gfx.print(F("Soft: "));
        gfx.setTextColor(TFT_WHITE);
        gfx.println(F("Emery Premeaux"));
        gfx.setCursor(90, 65);
        gfx.println(F("Taylan Ayken"));
        gfx.setCursor(0, 95);
        gfx.setTextColor(TFT_CYAN);
        gfx.print(F("Network: "));
        gfx.setTextColor(TFT_WHITE);
        gfx.println(F("Chris Shannon"));
        gfx.setCursor(0, 125);
        gfx.setTextColor(TFT_YELLOW);
        gfx.print(F("Solder: "));
        gfx.setTextColor(TFT_WHITE);
        gfx.println(F("Renee Steiner"));
        gfx.setCursor(0, 150);
        gfx.setTextColor(TFT_LIGHTGREY);
        gfx.println(F("      Arduino, TcMenu"));
        gfx.setCursor(0, 180);
        gfx.println(F("     Kicad, Platform.io"));
        gfx.setCursor(0, 210);
        gfx.setTextColor(TFT_RED);
        gfx.println(F("      FLOSS FOREVER!"));
        aboutState++;
    }
    break;

    case 1:
    {
        if (clicked)
        {
            renderer.giveBackDisplay();
            aboutState = 0;
        }
    }
    break;
    }
}

void CALLBACK_FUNCTION about(int id)
{
    renderer.takeOverDisplay(AboutCallback);
}

/****************************************************************************
 *                     Name Badge Mode
 ****************************************************************************/
int NBMState = 0;
void NameBadgeModeCallback(unsigned int encoderValue, RenderPressMode clicked)
{
    // At this point clicked is the status of the select button
    // it can be RPRESS_NONE, RPRESS_PRESSED or RPRESS_HELD
    // encoderValue is the current value of the rotary encoder
    String uName = menuSetupName.getTextValue();

    switch (NBMState)
    {
    case 0:
    {
        gfx.fillScreen(TFT_BLACK);
        gfx.setTextSize(2);
        gfx.setTextColor(TFT_WHITE);
        gfx.setTextDatum(MC_DATUM);
        gfx.drawString(uName, 140, 120);
        gfx.setTextDatum(TL_DATUM);
        NBMState++;
    }
    break;

    case 1:
    {
        if (clicked)
        {
            gfx.setTextSize(1);
            renderer.giveBackDisplay();
            aboutState = 0;
            NBMState = 0;
        }
    }
    break;
    }
}



/****************************************************************************
 *                     SETUP
 ****************************************************************************/
void setup()
{

    pinMode(USR_LED, OUTPUT);
    digitalWrite(USR_LED, HIGH);
    // this is the padding widget to push the menu widgets left (due to the curved corner).
    iconspadWidget.setCurrentState(1);
    Serial.begin(115200);

    Serial.println("In Setup()");

    // pull USER preferences...
    Global::preferences.begin("User", false);
    UserName = Global::preferences.getString("UserName", "Anonymous");
    Global::preferences.end();
    // set values in menu...
    // string to char array..
    int n = UserName.length();
    char namechar[n + 1];
    strcpy(namechar, UserName.c_str());
    menuSetupName.setTextValue(namechar);

    // pull SYSTEM preferences...
    Global::preferences.begin("System", false);
    BackLight = Global::preferences.getInt("BackLight", 5); // 0 indexed. 5 sets to 60%
    BadgeMode = Global::preferences.getInt("BadgeMode", 0);
    Global::Global::preferences.end();
    // map the value for PWM output
    int set = map(BackLight, 0, 9, 10, 255);
    // configure LED PWM functionalitites
    ledcSetup(ledChannel, freq, resolution);
    // attach the channel to the GPIO to be controlled
    ledcAttachPin(BACKLIGHT_PIN, ledChannel);
    ledcWrite(ledChannel, set);
    // set values in menu...
    menuSetupBadgeMode.setCurrentValue(BadgeMode);
    menuSetupBacklight.setCurrentValue(BackLight);

    Serial.println("getting WiFi Setttings");

    getWiFiSettings();
     Global::WiFi_Good = false;


    Serial.println("getting MQTT Settings");

    getMQTTsettings();


    // pull GAME preferences...
    // This is for game settings, scores, etc..
    Global::preferences.begin("Games", false);
    //      most games will get their prefs when launched
    Global::preferences.end();
    // set values in menu...
    Serial.println("Getting UUID");
    getUUID();

    init_TempHumidity();

    // prep menu and additional items

    Serial.println("Setting up switches and menu");

    switches.init(ioUsingArduino(), SWITCHES_NO_POLLING, true);

    Serial.printf("Width: %u  Height: %u \n", gfx.width(), gfx.height());

    gfx.begin();

    showImages();

    delay(500);

    setupMenu();

    // additional switch listeners
    switches.addSwitchListener(A_PIN, &keyListener, 25, false);
    switches.addSwitchListener(B_PIN, &keyListener, 25, false);

    renderer.setFirstWidget(&iconspadWidget);

    /****************************************************************************
     *    configure the device based on the set badge mode
     ****************************************************************************/
    switch (BadgeMode)
    {
    case 0:
    { // ******************** Normal Mode ********************
        // jump straight to the menu
    }
    break;

    case 1:
    { // ******************** Namebadge Mode ********************
        // Take over the display and print the user's name on the screen, with animation
        // wait for button press, then return to normal mode.
        renderer.takeOverDisplay(NameBadgeModeCallback);
    }
    break;
        // add additional badge modes here..
        // ******************** Default ********************
    default:
    {
        // if you got here something went seriously wrong!!
    }
    break;
    }

    // add tasks to taskmanagerIO
    // we dont need an ID for the icon task, as it will always run:
    taskManager.scheduleFixedRate(1, updateIconsTask, TIME_SECONDS);

    // these tasks we may stop and restart later, so we need the task ID
    Global::SenserUpdateTaskID = taskManager.scheduleFixedRate(1, SensorsMenu_Update, TIME_SECONDS);
    Global::ConnectWiFiTaskID = taskManager.scheduleFixedRate(1, Do_WiFi_FSM, TIME_SECONDS);

    if (menuSetupWiFiEnableWiFi.getBoolean() == true)
    { 
        Global::WiFi_DoReset = true;
    }

    Serial.println("Starting Loop...");
    digitalWrite(USR_LED, LOW);
}



/****************************************************************************
 *                     LOOP
 ****************************************************************************/
void loop()
{
    taskManager.runLoop();
}

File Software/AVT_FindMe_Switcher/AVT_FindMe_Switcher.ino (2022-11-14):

/* for some reason, has a difficult time in VScode platform.io.
 *  code works perfect from Arduino ide, but in platform.io, task loop never stops (no respect of interval value)
 *  and it goes crazy.
 *  Also usually locks up for a long time on boot before starting.
 */

#include "TaskManagerIO.h"

// Load Wi-Fi library
#include <WiFi.h>
#include "Adafruit_MQTT.h"
#include "Adafruit_MQTT_Client.h"

const int BatteryPin = 34;
const float BatDivScale = 2.13;

// AP stuff
const char* AP_SSID    = "FIND_ME_1";
const char* AP_PASSWORD = "avtokyo2022";
IPAddress IP = IPAddress (10, 10, 2, 6); // curly braces
//IPAddress gateway = IPAddress (10, 10, 2, 8); // not curly braces
IPAddress NMask = IPAddress (255, 255, 255, 0); // not curly braces


// Wifi client stuff
const char* CLIENT_SSID =       "YOURAP";
const char* CLIENT_PASSWORD =   "YOURAPPASSWORD";

// MQTT stuff
#define AIO_SERVER      "YOURMQTTSERVERIP"    // URL or IP address
#define AIO_SERVERPORT  1883                   // use 8883 for SSL
#define AIO_USERNAME    ""
#define AIO_KEY         ""
WiFiClient client;
Adafruit_MQTT_Client mqtt(&client, AIO_SERVER, AIO_SERVERPORT, AIO_USERNAME, AIO_KEY);

// TaskManager stuff
int interval = 30;    // time in seconds to change to client and update mqtt battery voltage

// visual indicator

const int ledPin =  2;
int ledState = LOW; 


bool switchClientMode() {
  // stop AP
   WiFi.disconnect();
 
  // join local wifi
  Serial.println("Switching to client mode");
  uint8_t wifiretry = 30;
  //WiFi.mode(WIFI_STA); //Optional
  WiFi.begin(CLIENT_SSID, CLIENT_PASSWORD);
  Serial.println("\nConnecting");
  while(WiFi.status() != WL_CONNECTED){
      Serial.print(".");
      wifiretry--;
      delay(100);
      if (wifiretry == 0) {
         Serial.println("Giving up on wifi, returning to AP mode");
         return false;
      }
  }
  Serial.println("\nConnected to the WiFi network");
  Serial.print("Local ESP32 IP: ");
  Serial.println(WiFi.localIP());
  return true;
}

bool postMQTT() {
  // post mqtt message
  int8_t ret;
  uint8_t retries = 3;
  while ((ret = mqtt.connect()) != 0) { // connect will return 0 for connected
       Serial.println(mqtt.connectErrorString(ret));
       Serial.println("Retrying MQTT connection in 5 seconds...");
       mqtt.disconnect();
       delay(5000);  // wait 1 second
       retries--;
       if (retries == 0) {
         return false;
       }
  }
  Serial.println("MQTT Connected!");
  float voltage = analogRead(BatteryPin) * (3.3/4096) * BatDivScale;
  char topic[255];
  strcpy(topic, "/AVTokyo2022/Find_Me/");
  strcat(topic, AP_SSID);
  strcat(topic, "/Voltage");
  Serial.println("Posting MQTT message");
  Adafruit_MQTT_Publish Voltage = Adafruit_MQTT_Publish(&mqtt, topic);
  Voltage.publish(voltage);
  return true;
}


bool switchAPMode () {
// stop wifi
  WiFi.disconnect();
  // restart AP
  Serial.println("Switching to AP mode");
  WiFi.softAP(AP_SSID, AP_PASSWORD);
  IPAddress IP = WiFi.softAPIP();
  Serial.println(IP);
  //server.begin();
  IPAddress myIP = WiFi.softAPIP();
  Serial.print("AP SSID: ");
  Serial.println(AP_SSID);
  Serial.print("AP IP address: ");
  Serial.println(myIP); 
}


void PostMQTTTask() {
  digitalWrite(ledPin, HIGH);
  bool switchedtoclient =   switchClientMode();
  if (switchedtoclient == true) {
    postMQTT();
  }
  switchAPMode();
  Serial.println("-----------------------");
  digitalWrite(ledPin, LOW);
}


void setup() {
  Serial.begin(115200);
  pinMode(ledPin, OUTPUT);
  switchAPMode();
  taskManager.scheduleFixedRate(interval, PostMQTTTask, TIME_SECONDS);  
}

void loop(){
  taskManager.runLoop();
 
}

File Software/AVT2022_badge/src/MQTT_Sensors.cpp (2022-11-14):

#include "MQTT_Sensors.h"
#include "Adafruit_MQTT.h"
#include "Adafruit_MQTT_Client.h"
#include "Preferences.h"
#include "AVT2022_badge_menu.h"
#include "variables.h"
#include "SaveScreen.h"
#include "secrets.h"

// temperature humidity sensor
#include "Adafruit_SHTC3.h"
Adafruit_SHTC3 shtc3 = Adafruit_SHTC3();

// Accelerometer
#include "kxtj3-1057.h"
#include "Wire.h"
float sampleRate = 6.25; // HZ - Samples per second - 0.781, 1.563, 3.125, 6.25, 12.5, 25, 50, 100, 200, 400, 800, 1600Hz
uint8_t accelRange = 2;  // Accelerometer range = 2, 4, 8, 16g
KXTJ3 myIMU(0x0E);       // Address can be 0x0E or 0x0F

#define BAT_SENSE 36           // ADC1 channel 0
const float BAT_SCALE = 2.25;   // ADC voltage * BAT_SCALE = real voltage.


bool Global::EnvSensor_ready; // temperature and humidity sensor initialized and working
bool Global::IMU_ready;       // accelerometer initialized and working
float Global::BatteryVoltage;
float Global::Temperature;
float Global::Humidity;
float Global::IMU_x;
float Global::IMU_y;
float Global::IMU_z;
bool Global::MQTT_GameToPost;
int Global::PostInterval = 5;
bool Global::MQTT_Enable; // to post or not to post? that is the question..
bool Global::MQTT_Good;   // true: mqtt connection is working
int rate = 1000;
int MQTTinterval = 1000;

/******************* MQTT basic config **************************/
#define Def_AIO_SERVERPORT 1883         // use 8883 for SSL
#define AIO_USERNAME ""
#define AIO_KEY ""

String AIO_SERVER = ""; 
String AIO_SERVERPORT = "1883";
const int MQTTInterval = 5; // 5 seconds

// Setup the MQTT client class by passing in the WiFi client and MQTT server and login details.
Adafruit_MQTT_Client mqtt(&Global::client, SECRET_SERVER, Def_AIO_SERVERPORT, AIO_USERNAME, AIO_KEY);

/************ Subscribes ************/
// Setup a feed called 'onoff' for subscribing to changes.
Adafruit_MQTT_Subscribe onoffbutton = Adafruit_MQTT_Subscribe(&mqtt, AIO_USERNAME "/avtokyo2022/onoff");

/************ topic feeds ************/
// ultimately:  append /uuid  like : /AVTokyo2022/[UUID]/Sensors/Test/Voltage
// Adafruit_MQTT_Publish VOLT = Adafruit_MQTT_Publish(&mqtt, AIO_USERNAME "/AVTokyo2022/Sensors/Voltage");
// Adafruit_MQTT_Publish TEMPERATURE = Adafruit_MQTT_Publish(&mqtt, AIO_USERNAME "/AVTokyo2022/Sensors/Temperature");
// Adafruit_MQTT_Publish HUMIDITY = Adafruit_MQTT_Publish(&mqtt, AIO_USERNAME "/AVTokyo2022/Sensors/Humidity");

// game feeds
//Adafruit_MQTT_Publish QUIZ = Adafruit_MQTT_Publish(&mqtt, AIO_USERNAME "/AVTokyo2022/Games/Quiz");
//Adafruit_MQTT_Publish SNEK = Adafruit_MQTT_Publish(&mqtt, AIO_USERNAME "/AVTokyo2022/Games/Snek");

/******************  initialize hardware **************************/

bool init_TempHumidity()
{
    // start Temperature / Humidity sensor
    if (!shtc3.begin())
    {
        Serial.println("Couldn't find SHTC3");
        Global::EnvSensor_ready = false;
        return false;
    }
    Serial.println("Found SHTC3 sensor");
    Global::EnvSensor_ready = true;
    return true;
}

bool init_IMU()
{
    if (myIMU.begin(sampleRate, accelRange) != 0)
    {
        Serial.print("Failed to initialize IMU.\n");
        Global::IMU_ready = false;
        return false;
    }
    else
    {
        Serial.print("IMU initialized.\n");
        // Detection threshold, movement duration and polarity
        myIMU.intConf(123, 1, 10, HIGH);
        uint8_t readData = 0;
        // Get the ID:
        myIMU.readRegister(&readData, KXTJ3_WHO_AM_I);
        Serial.print("IMU address: 0x");
        Serial.println(readData, HEX);
        Global::IMU_ready = true;
        return true;
    }
}

/******************  Updating sensors **************************/

bool envSensor_Update()
{
    sensors_event_t humidity, temp;
    Global::EnvSensor_ready = shtc3.getEvent(&humidity, &temp); // populate temp and humidity objects with fresh data
    Global::Temperature = temp.temperature;
    Global::Humidity = humidity.relative_humidity;
    if (Global::EnvSensor_ready == true)
    {
        return true;
    }
    else
    {
        Global::Temperature = 0;
        Global::Humidity = 0;
        return false;
    }
}

void batterySensor_Update()
{
    /* battery measurement:
     * Voltage divider is set to divide by 0.75
     * 4.1 V Bat = 3.075V ADC
     * 3.0 V Bat = 2.25V ADC
     * https://randomnerdtutorials.com/esp32-adc-analog-read-arduino-ide/
     */

    int adctemp = analogRead(BAT_SENSE);
    float adcVolt = adctemp * (3.3 / 4096);

    //       Serial.print("adc: "); Serial.print(adctemp); Serial.print("   "); Serial.print("adc volt: "); Serial.println(adcVolt);
    Global::BatteryVoltage = adcVolt * BAT_SCALE;
    menuSensorsBatteryVoltage.setFloatValue(Global::BatteryVoltage);
    //       Serial.print("battery: "); Serial.println(Global::BatteryVoltage);
    //       Serial.println();
}

void IMU_Update()
{
    if (Global::IMU_ready == false)
    {
        // give it another try...
        init_IMU();
    }
    myIMU.standby(false);
    Global::IMU_x = myIMU.axisAccel(X);
    Global::IMU_y = myIMU.axisAccel(Y);
    Global::IMU_z = myIMU.axisAccel(Z);
    myIMU.standby(true);
}

/******************  sending data to the menu **************************/

void SensorsMenu_Update()
{
    batterySensor_Update();
    menuSensorsBatteryVoltage.setFloatValue(Global::BatteryVoltage);

    // try the env sensor
    //   if (Global::EnvSensor_ready == false) {
    // give it another try...
    //       init_TempHumidity();
    //   }
    envSensor_Update(); // will fill temperature and humidity with zero if read fails, so we can update menu regardless.
    menuSensorsTemperature.setFloatValue(Global::Temperature);
    menuSensorsHumidity.setFloatValue(Global::Humidity);
}

void getMQTTsettings()
{

    // pull MQTT settings
    Global::preferences.begin("MQTT", false);
    Global::MQTT_Enable = Global::preferences.getBool("MQTTenable", true);
    AIO_SERVER = Global::preferences.getString("MQTTbroker", AIO_SERVER);
    AIO_SERVERPORT = Global::preferences.getInt("MQTTport", 1883);
    MQTTinterval = Global::preferences.getInt("MQTTinterval", MQTTInterval);
    Global::preferences.end();
    Serial.print("mqtt port: ");
    Serial.println(AIO_SERVERPORT);
    // string to char array..
    int mqttservlen = AIO_SERVER.length() + 1;
    char brokerchar[mqttservlen];
    AIO_SERVER.toCharArray(brokerchar, mqttservlen);
    strcpy(brokerchar, AIO_SERVER.c_str());
    // set menu text
    menuSetupMQTTEnable.setBoolean(Global::MQTT_Enable);
    menuSetupMQTTBroker.setTextValue(brokerchar);
    menuSetupMQTTPort.setCurrentValue(AIO_SERVERPORT.toInt());
    menuSetupMQTTPostInterval.setCurrentValue(MQTTinterval);
}
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
